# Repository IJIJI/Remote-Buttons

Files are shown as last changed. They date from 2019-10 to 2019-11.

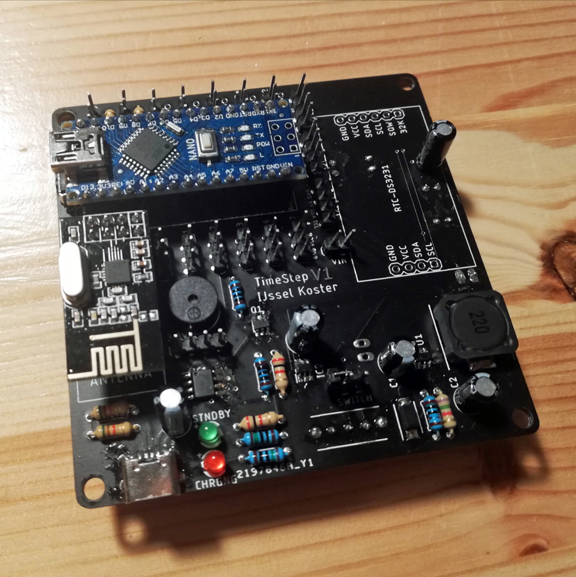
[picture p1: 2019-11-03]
img/Timestep2.jpg

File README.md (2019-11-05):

# TimeStep V0.5
 Timestep V0.5 is the alpha version of the TimeStep hardware platform. 

<!-- <img src="img\Timestep.png" alt="TimeStep V1" style="border-radius:20px; width:40%; margin-left:5%; margin-right:4%; box-shadow: 7px 7px 10px grey;">
<img src="img\Timestep2.jpg" alt="TimeStep V1" style="border-radius:20px; width:40%; margin-left:4%; margin-right:5%; box-shadow: 7px 7px 10px grey;"> -->

## TO DO
* Implement the battery sensor.
* Add a dedicated settings menu.
* Add Classes.
* Add a lapped mode.
* Add a chess mode.
* Add lapptimes to the timed and re-end modes.
* Fix images in readme.md

##### **Prepare for** ***V1.0***
* Add a description.
* Complete adding comments in the code.
* Add wireless connectivity.
  * Complete the pairing menu.
* Change the buttonpressen in the timed modes to the bPress function.

### Fixes
* Fix time set so that all the digits update.
* Fix double press problem
* Fix freezing issue.
* Split into multuple files.
  * Fix Combined branch.
  * Merge Combined branch.

### thoughts
* Add a (esp8266) wifi chip?
* Add interrupts?

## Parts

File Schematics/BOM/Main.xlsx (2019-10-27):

Qty | Value | Device | Package | Parts | Description | Selected: | Ordered
2 |  | LED3MM | LED3MM | CHRGD, CHRGNG | LED | 1
2 |  | MICROBUILDER_SOLDERJUMPERWAVE | MICROBUILDER_SOLDERJUMPER_WAVE | ADDR0, ADDR1 | SMD Solder JUMPER | 1
4 |  | PINHD-1X2 | 1X02 | BATT, BATT_VIN, SWITCH, VIN | PIN HEADER | 1
13 |  | PINHD-1X3 | 1X03 | A0, A1, A2, A3, A6, A7, D2, D3*, D4, D5*, D6*, D7, D8 | PIN HEADER | 1
4 |  | PINHD-1X4 | 1X04 | 3.3V, I2C_1, I2C_2, I2C_3 | PIN HEADER | 1
1 | 0.1/1% (PT2512FK-070R1L) | R-EU_R2512 | R2512 | R17 | RESISTOR, European symbol | 1
1 | 47μF | CPOL-EUE2-5 | E2-5 | C9 | POLARIZED CAPACITOR, European symbol | 1
2 | 22μF | CPOL-EUE2-5 | E2-5 | C1, C2 | POLARIZED CAPACITOR, European symbol | 1
1 | 10μF | CPOL-EUE2-5 | E2-5 | C8 | POLARIZED CAPACITOR, European symbol | 1
2 | 4.7μF | CPOL-EUE2-5 | E2-5 | C4, C5 | POLARIZED CAPACITOR, European symbol | 1
2 | 0.1μF | CPOL-EUE2-5 | E2-5 | C6, C7 | POLARIZED CAPACITOR, European symbol | 1
11 | 10kΩ | R-EU_0204/7 | 0204/7 | R6, R7, R8, R9, R10, R11, R12, R15, R16, R18, R19 | RESISTOR, European symbol | 1
1 | 7.5kΩ | R-EU_0204/7 | 0204/7 | R1 | RESISTOR, European symbol | 1
2 | 5.1kΩ | R-EU_0204/7 | 0204/7 | R20, R21 | RESISTOR, European symbol | 1
1 | 2kΩ | R-EU_0204/7 | 0204/7 | R5 | RESISTOR, European symbol | 1
2 | 1kΩ | R-EU_0204/7 | 0204/7 | R2, R13 | RESISTOR, European symbol | 1
2 | 150Ω | R-EU_0204/7 | 0204/7 | R3, R4 | RESISTOR, European symbol | 1
2 | 100Ω | R-EU_0204/7 | 0204/7 | R14, R22 | RESISTOR, European symbol | 1
1 | 22μH | APW12A45M220 | INDPM125125X450M | L1 | Power Inductors 22uH +/-20% SMD,12.5X12.5mm RoHS | 1
1 | AMS1117-3.3 | AMS1117-3.3 | SOT229P700X180-4N | IC5 | 1A LOW DROPOUT VOLTAGE REGULATOR, SOT-223 | 1
1 | ARDUINO-NANO-3.0 | ARDUINO-NANO-3.0 | ARDUINO-NANO-3.0 | M1 | Arduino Nano 3.0 and compatible devices | 1 | 1
1 | FS312F-G | FS312F-G | SOT95P280X145-6M | IC2 | One Cell Lithium-ion/Polymer Battery Protection IC | 1
1 | FS8205 | FS8205 | FS8205 | Q1 | DUAL N-CHANNEL ENHANCEMENT MODE POWER MOFSET | 1
1 | HNB09A05 | HNB09A05 | HNB09A05 | BUZZER | Buzzers Magnetic YES 3000+/-300Hz 5V 4 ~ 8V 9mm DIP RoHS | 1
1 | INA219AIDR | INA219AIDR | SOIC127P600X175-8N | IC4 | 26-V, Bidirectional, Zero-Drift, High-Side, I2C Out Current/Power Monitor | 1
1 | MCP73831/OT | MCP73831/OT | SOT23-5L | IC1 | MCP73831/2 | 1
1 | MT3608 | MT3608 | SOT95P280X145-6N | U1 | High Efficiency 1.2MHz 2A Step Up Converter | 1
1 | RTC-DS3231-AT24C32 | RTC-DS3231-AT24C32 | RTC-DS3231-AT24C32 | RTC-DS3231 | RTC Module with Battery and EEPROM based on DS3231 and AT24C32 chips | 1 | 1
1 | SS-12F44-G5 | SS-12F44-G5 | SS12F44G5 | S1 | Toggle Switches Plugin RoHS | 1
1 | SS34 | SS34 | DIOM5436X244M | D1 | Schottky Barrier Diodes (SBD) SMA(DO-214AC) RoHS | 1
1 | TS6643ZJ | TS6643ZJ | TS6643ZJ | S2 | Electrical Switches Through Hole | 1
1 | TYPE-C-31-M-17 | TYPE-C-31-M-17 | TYPEC31M17 | J1 | USB Connectors 6 Receptacle 1 RoHS | 1
1 | WIRELESS-NRF24L01 | WIRELESS-NRF24L01 | WIRELESS-NRF24L01 | NRF24L01 | 2.4 GHz Wireless Module based on NRF24L01 chip | 1 | 1

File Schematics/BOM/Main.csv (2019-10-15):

Qty | Value | Device | Package | Parts | Description
2 |  | LED3MM | LED3MM | CHRGD, CHRGNG | LED
2 |  | MICROBUILDER_SOLDERJUMPERWAVE | MICROBUILDER_SOLDERJUMPER_WAVE | ADDR0, ADDR1 | SMD Solder JUMPER
4 |  | PINHD-1X2 | 1X02 | BATT, BATT_VIN, SWITCH, VIN | PIN HEADER
13 |  | PINHD-1X3 | 1X03 | A0, A1, A2, A3, A6, A7, D2, D3*, D4, D5*, D6*, D7, D8 | PIN HEADER
4 |  | PINHD-1X4 | 1X04 | 3.3V, I2C_1, I2C_2, I2C_3 | PIN HEADER
1 | 0.1/1% (PT2512FK-070R1L) | R-EU_R2512 | R2512 | R17 | RESISTOR, European symbol
2 | 0.1uF | CPOL-EUE2-5 | E2-5 | C6, C7 | POLARIZED CAPACITOR, European symbol
2 | 100Ω | R-EU_0204/7 | 0204/7 | R14, R22 | RESISTOR, European symbol
11 | 10kΩ | R-EU_0204/7 | 0204/7 | R6, R7, R8, R9, R10, R11, R12, R15, R16, R18, R19 | RESISTOR, European symbol
1 | 10uF | CPOL-EUE2-5 | E2-5 | C8 | POLARIZED CAPACITOR, European symbol
2 | 150Ω | R-EU_0204/7 | 0204/7 | R3, R4 | RESISTOR, European symbol
1 | 1kΩ | R-EU_0204/7 | 0204/7 | R2 | RESISTOR, European symbol
1 | 2.2kΩ | R-EU_0204/7 | 0204/7 | R5 | RESISTOR, European symbol
1 | 22uH | APW12A45M220 | INDPM125125X450M | L1 | Power Inductors 22uH +/-20% SMD,12.5X12.5mm RoHS
2 | 22μF | CPOL-EUE2-5 | E2-5 | C1, C2 | POLARIZED CAPACITOR, European symbol
1 | 2kΩ | R-EU_0204/7 | 0204/7 | R13 | RESISTOR, European symbol
2 | 4.7μF | CPOL-EUE2-5 | E2-5 | C4, C5 | POLARIZED CAPACITOR, European symbol
1 | 47uF | CPOL-EUE2-5 | E2-5 | C9 | POLARIZED CAPACITOR, European symbol
2 | 5.1kΩ | R-EU_0204/7 | 0204/7 | R20, R21 | RESISTOR, European symbol
1 | 7.5kΩ | R-EU_0204/7 | 0204/7 | R1 | RESISTOR, European symbol
1 | AMS1117-3.3 | AMS1117-3.3 | SOT229P700X180-4N | IC5 | 1A LOW DROPOUT VOLTAGE REGULATOR, SOT-223
1 | ARDUINO-NANO-3.0 | ARDUINO-NANO-3.0 | ARDUINO-NANO-3.0 | M1 | Arduino Nano 3.0 and compatible devices
1 | FS312F-G | FS312F-G | SOT95P280X145-6M | IC2 | One Cell Lithium-ion/Polymer Battery Protection IC
1 | FS8205 | FS8205 | FS8205 | Q1 | DUAL N-CHANNEL ENHANCEMENT MODE POWER MOFSET
1 | HNB09A05 | HNB09A05 | HNB09A05 | BUZZER | Buzzers Magnetic YES 3000+/-300Hz 5V 4 ~ 8V 9mm DIP RoHS
1 | INA219AIDR | INA219AIDR | SOIC127P600X175-8N | IC4 | 26-V, Bidirectional, Zero-Drift, High-Side, I2C Out Current/Power Monitor
1 | MCP73831/OT | MCP73831/OT | SOT23-5L | IC1 | MCP73831/2
1 | MT3608 | MT3608 | SOT95P280X145-6N | U1 | High Efficiency 1.2MHz 2A Step Up Converter
1 | RTC-DS3231-AT24C32 | RTC-DS3231-AT24C32 | RTC-DS3231-AT24C32 | RTC-DS3231 | RTC Module with Battery and EEPROM based on DS3231 and AT24C32 chips
1 | SS-12F44-G5 | SS-12F44-G5 | SS12F44G5 | S1 | Toggle Switches Plugin RoHS
1 | SS34 | SS34 | DIOM5436X244M | D1 | Schottky Barrier Diodes (SBD) SMA(DO-214AC) RoHS
1 | TS6643ZJ | TS6643ZJ | TS6643ZJ | S2 | Electrical Switches Through Hole
1 | TYPE-C-31-M-17 | TYPE-C-31-M-17 | TYPEC31M17 | J1 | USB Connectors 6 Receptacle 1 RoHS
1 | WIRELESS-NRF24L01 | WIRELESS-NRF24L01 | WIRELESS-NRF24L01 | NRF24L01 | 2.4 GHz Wireless Module based on NRF24L01 chip

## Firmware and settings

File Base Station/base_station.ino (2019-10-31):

#include <Arduino.h>
#include <Wire.h>
#include <EEPROM.h>
#include <LiquidCrystal_I2C.h>
#include "RTClib.h"

/*
* Not Up to date.
System with display on uses about 56ma.
System without display uses about 41ma.
*/

LiquidCrystal_I2C lcd(0x27,16,2);  // set the LCD address to 0x27 for a 16 chars and 2 line display
RTC_DS3231 rtc;

//Modes
const char modes[10][11] = {"Timed", "Re-end", "Lapped", "Quiz", "PowerPoint", "Button Set","Time Set", "Pairing", "9", "10"};

// Pinouts
#define buzzer
#define buttonUp 3
#define buttonDown 4
#define buttonMain 5
#define ledMain 6

int buttons = 1; // default terminals + base stations

//#define menuLoop
#define menuMax 7
#define menuMin 1

//The button max limit, increasing this higher than necessary may increase scan times.
#define buttonMax 10

#define screenTimeOut 1

#define setUpAdress 6 // this is how the firmware knows if it has been set up for the first time
#define adress1 7 // Here the button amount is stored

const int EEPid[6] {100, 240, 129, 92, 7, 9}; // This is the code for the firmware to recognize if it has been started before.
const int setUpId = 98;  //This is the code for the firmware to recognize if it has been setup.
//Communication codes.
const int PairCode[buttonMax] {101, 102, 103, 104, 105, 106, 107, 108, 109, 110};
const int trigCode[buttonMax] {151, 152, 153, 154, 155, 156, 157, 158, 159, 160};


// Do not check below if you don't know what you are doing.
int Menu = 1;
int cMenu = 0;
int cHour = 99;
int cMinute = 99;
int cSecond = 99;
bool dispUpdate = false;

bool firstStart = false;


#ifdef screenTimeOut
bool DispOn;
int lastActTime;
#endif

int x;

void setup()
{
  //set the pinmodes.
  pinMode(buttonUp, INPUT_PULLUP); 
  pinMode(buttonDown, INPUT_PULLUP);
  pinMode(buttonMain, INPUT_PULLUP); 
  pinMode(ledMain, OUTPUT);

  // Print an initialization message to the LCD.
  lcd.init();  // initialize the lcd. 
  lcd.backlight(); //Turn on the backlight
  bool DispOn = true; //Let the system know that the display is on.
  lastActTime = secTime(); //Set the last active time to the current time.
  digitalWrite(ledMain, HIGH); //Turn on ledMain for setup.
  lcd.setCursor(2,0);
  lcd.print("initializing");

  if (EEPROMcheck() == false){ // CHeck if the firmware has been started before.
    lcd.print("*");
    firstStart = true;
  }

  lcd.setCursor(0,1);
  lcd.print("[              ]"); //Make a status bar
  delay(200);
  for (x; x <= 13; x++){

    lcd.setCursor(x + 1,1);
    lcd.print("=");
    delay(70); 
  }
  lcd.clear(); //Clear the LCD
  digitalWrite(ledMain, LOW); // Turn off the button ledMain
  if (firstStart == true || EEPROM.read(setUpAdress) != setUpId){ // First time setup.
    prgrm(5);
    prgrm(4);
    if (buttons > 1){
      prgrm(6);
    }
    EEPROM.write(setUpAdress, setUpId);
  }
}


void loop()
{
  DateTime now = rtc.now(); //define rtc.now
  if (digitalRead(buttonMain) == LOW && DispOn == true){ // check if buttonMain is pressed.
    bPress(false);
    prgrm(Menu);
  }
  if (digitalRead(buttonUp) == LOW && DispOn == true){ //check if the buttonUp is pressed
    Menu = Menu + 1;
    while (digitalRead(buttonUp) == LOW){delay(1);}
  }
  if (digitalRead(buttonDown) == LOW && DispOn == true){ //check if the buttonDown is pressed
    Menu = Menu - 1;
    while (digitalRead(buttonDown) == LOW){delay(1);}
  }
  if(Menu > menuMax){ // CHeck if the menu is over the max.
    #ifdef menuLoop
    Menu = menuMin;
    #else
    Menu = menuMax;
    #endif
  }
  if(Menu < menuMin){ //check if the menu is under the min
    #ifdef menuLoop
    Menu = menuMax;
    #else
    Menu = menuMin;
    #endif
  }
  #ifdef screenTimeOut // Manages the backlight.
  if (digitalRead(buttonDown) == LOW || digitalRead(buttonUp) == LOW || digitalRead(buttonMain) == LOW){
    lastActTime = secTime();
    
    while(digitalRead(buttonDown) == LOW || digitalRead(buttonUp) == LOW || digitalRead(buttonMain) == LOW && DispOn == false){delay(1);}
    
  }
  if (secTime() >= lastActTime + 60 * screenTimeOut && DispOn == true){
    lcd.noBacklight();
    DispOn = false;
  }
  else if (secTime() < lastActTime + 60 * screenTimeOut && DispOn == false){
    lcd.backlight();
    DispOn = true;
    dispUpdate = true;
  }
  #endif


  if (Menu != cMenu || dispUpdate == true){ //check if the supposed menu is different from the current menu
    cMenu = Menu;
    lcd.setCursor(0,0);
    lcd.print("                ");
    lcd.setCursor(0,0);
    lcd.print("Mode: ");
    lcd.print(modes[cMenu - 1]);
    delay(200);
  }
  if (now.hour() != cHour || dispUpdate == true){ //check if the current time is different from the supposed time
    cHour = now.hour();
    lcd.setCursor(4,1);
    lcd.print("   ");
    lcd.setCursor(4,1);
    lcdDigitPrint(now.hour(), 2);
    lcd.print(":");
  }
  if (now.minute() != cMinute || dispUpdate == true){ //check if the current time is different from the supposed time
    cMinute = now.minute();
    lcd.setCursor(7,1);
    lcd.print("   ");
    lcd.setCursor(7,1);
    lcdDigitPrint(now.minute(), 2);
    lcd.print(":");
  }
  if (now.second() != cSecond || dispUpdate == true){ //check if the current time is different from the supposed time
    cSecond = now.second();
    lcd.setCursor(10,1);
    lcd.print("   ");
    lcd.setCursor(10,1);
    lcdDigitPrint(now.second(), 2);

  }

  if (dispUpdate == true){
    dispUpdate = false;
  }
}


void lcdDigitPrint(int inVar, int digits){ // A function that prints a variable to the lcd with a fixed digit count.
  int zeros;
  if (inVar < int(pow(10, digits - 1))){
    for(int x = 1; x < digits; x++){
      if(inVar < int(pow(10, x))){
        zeros = digits - x;
        for(x = 1; x <= zeros; x++){
          lcd.print("0");
        }
        lcd.print(inVar);
        break;
      }

    }

  }
  else{
    lcd.print(inVar);
  }
}
void bPress(int sCheck){ //Wait for when button is released + ledMain
  if (sCheck == true){
    while(digitalRead(buttonMain) == LOW){delay(5);}
    while(digitalRead(buttonMain) != LOW){delay(5);}
  }
  digitalWrite(ledMain, HIGH);
  while (digitalRead(buttonMain) == LOW){delay(5);}
  digitalWrite(ledMain, LOW);
  // delay(20);
}

int getMil(float sec){ // Converts inputted seconds to minutes and seconds and returns the remainder.
  int sec2 = sec * 100;
  sec = sec2 % 100;
  return abs(sec);
}
int getSec(float sec){ // Converts inputted seconds to miliseconds, seconds and minutes and returns seconds.
  int sec2 = sec;
  sec = sec2 % 60;
  return sec;

}
int getMin(float sec){ // Converts inputted seconds to miliseconds seconds and minutes and returns minutes.
  int sec2 = sec;
  int mins;
  mins = round((sec2 / 60));
  return mins;
}
int secTime() { // gets the current time in seconds (mith a descimal)
  DateTime now = rtc.now();
  int secTime;
  secTime = now.second() + now.minute() * 60 + now.hour() * 60 * 60;
  return secTime;
}
int timeDiv(int x){ //gets the time depending on the number.
  DateTime now = rtc.now();
  int result;
  if (x == 0){
    result = now.hour();
  }
  else if (x == 1){
    result = now.minute();
  }
  else if (x == 2){
    result = now.second();
  }
  return result;

}
int EEPROMcheck(){ // compares the eeprom for the EEPid's and returns false if unfamiliar and rewrites the eeprom to EEPid.
  bool familiar = true;
  for(int x = 0; x < 6; x++){
    if (EEPROM.read(x) != EEPid[x]){
      familiar = false;
    }
  }
  if (familiar == false){
    for (int x = 0; x < EEPROM.length(); x++){
      EEPROM.write(x, 0);
    }
    for (int x = 0; x < 6; x++){
      EEPROM.write(x, EEPid[x]);
    }
    EEPROM.write(adress1, buttons);
  }
  if (familiar == true){
    buttons = EEPROM.read(adress1);
  }
  return familiar;
}



//TODO VV should be moved to seperate files

void prgrm(int menu) { // these are the different programs found in the menu.
  DateTime now = rtc.now();
  
  if (menu == 1 || menu == 2)
  {
    int pedButtons = 0;
    int bMenu = 3;
    int cBMenu = 99;
    float tStart = 0;
    float time = 0;
    int actived[buttonMax] = {0, 0, 0, 0, 0, 0, 0, 0, 0, 0}; 

    bool buttonMainActive = 0;

    lcd.clear();
    lcd.setCursor(0,0);
    lcd.print("Time:");
    lcd.setCursor(1,1);
    lcd.print("Press to start");
    while(digitalRead(buttonMain) != LOW){delay(5);}
    digitalWrite(ledMain, HIGH);
    while(digitalRead(buttonMain) == LOW){delay(5);}
    lcd.clear();
    lcd.setCursor(0,0);
    lcd.print("Time:");
    lcd.setCursor(0,1);
    lcd.print("Left:");
    tStart = millis();
    while(pedButtons < buttons){
      time = (millis() - tStart) / 1000;
      lcd.setCursor(6, 0);
      lcdDigitPrint(getMin(time), 2);
      lcd.print(":");
      lcdDigitPrint(getSec(time), 2);
      lcd.print(".");
      lcd.print(getMil(time));
      lcd.setCursor(6,1);
      lcd.print(buttons-pedButtons);
      if (digitalRead(buttonMain) == LOW || actived[0] == 1){
        actived[0] = 1;
        digitalWrite(ledMain, LOW);
      }
      for (int x = 1; x <= buttons; x++){
        //check if input car = trigCode[x - 1]
      }
      pedButtons = 0;
      for (int x = 0; x <= buttons; x++){
        pedButtons = pedButtons + actived[x];
      }

      

    }
    lcd.setCursor(6,1);
    lcd.print("Completed!");
    bPress(true);
    
    


  }
  else if (menu == 3){
    float tStart;
    float time;
    double lapTime[] = {};
    int laps = 0;

    int tMenu = 0;
    int CtMenu = 99;

    lcd.clear();
    lcd.setCursor(0,0);
    lcd.print("Time:");
    lcd.setCursor(1,1);
    lcd.print("Press to start");
    while(digitalRead(buttonMain) != LOW){delay(5);}
    digitalWrite(ledMain, HIGH);
    while(digitalRead(buttonMain) == LOW){delay(5);}
    lcd.clear();
    lcd.setCursor(0,0);
    lcd.print("Time:");
    lcd.setCursor(0,1);
    lcd.print("Laps:");
    tStart = millis();
    while(digitalRead(buttonUp) == HIGH && digitalRead(buttonDown) == HIGH){
      time = (millis() - tStart) / 1000;
      lcd.setCursor(6, 0);
      lcdDigitPrint(getMin(time), 2);
      lcd.print(":");
      lcdDigitPrint(getSec(time), 2);
      lcd.print(".");
      lcd.print(getMil(time));
      lcd.setCursor(6,1);
      lcd.print(laps);
      if (digitalRead(buttonMain) == LOW /* || Radio signal == active */){
        lapTime[laps] = time;
        laps++; 
      }

    }
    
    while (digitalRead(buttonMain) == HIGH){
      
      if (digitalRead(buttonUp) == LOW && cMenu < laps - 1){
        cMenu++;
      }
      if (digitalRead(buttonDown) == LOW && cMenu > 0){
        cMenu--;
      }
    
      if (tMenu != CtMenu){  
        CtMenu = tMenu;
        lcd.setCursor(0,0);
        lcd.print(tMenu);
        lcd.print(": ");
        lcdDigitPrint(getMin(lapTime[tMenu]), 2);
        lcd.print(":");
        lcdDigitPrint(getSec(lapTime[tMenu]), 2);
        lcd.print(".");
        lcd.print(getMil(lapTime[tMenu]));
        
        lcd.setCursor(0,1);
        lcd.print(tMenu + 1);
        lcd.print(": ");
        lcdDigitPrint(getMin(lapTime[tMenu + 1]), 2);
        lcd.print(":");
        lcdDigitPrint(getSec(lapTime[tMenu + 1]), 2);
        lcd.print(".");
        lcd.print(getMil(lapTime[tMenu + 1]));
      
      }

    }
    bPress(false);
  }
  else if (menu == 4){
    int bPressd = 999;
    lcd.clear();
    lcd.setCursor(6,0);
    lcd.print("Quiz");
    lcd.setCursor(1,1);
    lcd.print("Press To Start");
    bPress(true);
    
  }
  else if (menu == 6){

    int cButtons = 99;
    lcd.clear();
    lcd.setCursor(0,0);
    lcd.print("Stations:");
    while(digitalRead(buttonMain) == LOW){delay(1);}
    while(digitalRead(buttonMain) != LOW){
      if (digitalRead(buttonUp) == LOW && buttons < buttonMax){
        buttons = buttons + 1;
        while(digitalRead(buttonUp) == LOW){delay(1);}
      }
      if (digitalRead(buttonDown) == LOW && buttons > 1){
        buttons = buttons - 1;
        while(digitalRead(buttonDown) == LOW){delay(1);}
      }

      if (cButtons != buttons){
        cButtons = buttons;
        lcd.setCursor(10, 0);
        lcd.print("       ");
        lcd.setCursor(10, 0);
        lcd.print(buttons);
      }
      

    }
    EEPROM.write(adress1, buttons);
    dispUpdate = true;
    lastActTime = secTime();
    bPress(false);
  }
  else if(menu == 7){

    int cTimeEdit = 0;
    char tOffset[3] = {0, 0, 0};
    const char tMaxLimits[3] = {24, 60, 60};
    char cSetTime[3] = {0, 0, 0};
    const char timeLocs[3] = {4, 7, 10};
    while(digitalRead(buttonMain) == LOW){delay(1);}
    lcd.clear();
    lcd.setCursor(0,0);
    lcd.print("Time:");
    while(cTimeEdit <= 2){

      if (timeDiv(cTimeEdit) + tOffset[cTimeEdit] != cSetTime[cTimeEdit] || timeDiv(cTimeEdit) + tOffset[cTimeEdit] == 0){ //check if the current time is different from the supposed time
        cSetTime[cTimeEdit] = timeDiv(cTimeEdit) + tOffset[cTimeEdit];
        lcd.setCursor(timeLocs[cTimeEdit],1);
        lcd.print("   ");
        lcd.setCursor(timeLocs[cTimeEdit],1);
        lcdDigitPrint(timeDiv(cTimeEdit) + tOffset[cTimeEdit], 2);
        if (cTimeEdit != 2){ 
          lcd.print(":");
        }
      }
      if (digitalRead(buttonMain) == LOW){
        cTimeEdit = cTimeEdit + 1;
        bPress(false);
      }
      if (digitalRead(buttonUp) == LOW && timeDiv(cTimeEdit) + tOffset[cTimeEdit] < tMaxLimits[cTimeEdit]){
        tOffset[cTimeEdit] = tOffset[cTimeEdit] + 1;
        while(digitalRead(buttonUp) == LOW){delay(1);}
      }
      if (digitalRead(buttonDown) == LOW && timeDiv(cTimeEdit) + tOffset[cTimeEdit] > 0){ 
        tOffset[cTimeEdit] = tOffset[cTimeEdit] - 1;
        while (digitalRead(buttonDown) == LOW){delay(1);}
      }
      
    }
    int hTime = timeDiv(0) + tOffset[0];
    int mTime = timeDiv(1) + tOffset[1];
    int sTime = timeDiv(2) + tOffset[2];
    rtc.adjust(DateTime(2019, 10, 15, hTime, mTime, sTime));


  }
  else if (menu == 7){
    while (digitalRead(buttonMain) == LOW){delay(1);}
    lcd.clear();
    lcd.setCursor(0,0);
    lcd.print("Hold Pair On");
    lcd.setCursor(0,1);
    lcd.print("Button:");
    for(int x = 2; x <= buttons; x++){
      lcd.setCursor(8,1);
      lcd.print("        ");
      lcd.setCursor(8,1);
      lcd.print(x);
      bPress(true);
      // send paircode paircode[x] to transmitters  
      // delay(300);
    }
    lcd.clear();
    if (buttons > 1){
      lcd.setCursor(0,0);
      lcd.print("Pairing complete!");
    }
    else {
      lcd.setCursor(3,0);
      lcd.print("No Buttons");
      lcd.setCursor(4,1);
      lcd.print("To Pair!");
    }
    delay(1000);
      
  }
  lcd.clear();
  dispUpdate = true;
  lastActTime = secTime();


}

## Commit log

2019-09-21 Fixed Time set 0 problem and led support
    [base_station.ino]
2019-09-21 Added a PCB Schematic.
    [station v1.fzz]
2019-09-22 Completed LED integration
2019-09-22 Added schematic v1
    [station v1.fzz]
2019-09-25 added pulldown resistors to pcb
    [station PCB v1.fzz]
2019-09-27 added minute formating to timer.
2019-09-27 Fixed the timer display format
    [base_station.ino]
2019-10-01 Added arduino.json to gitignore
    [station PCB v1+.fzz, station PCB v1.fzz]
2019-10-06 Added BOM
    [Main.csv]
2019-10-15 added rf library
    [Main.csv, Main.xlsx, station PCB v1+.fzz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]
2019-10-21 Revert "Changed back to single file, see combined"
    This reverts commit 0e1d58947b35420be689b455369c2b491d9700fd.
    [base_station.ino]
2019-10-21 Revert "Revert "Changed back to single file, see combined""
    This reverts commit f698fb8d14c6b5069cf7f1855aeea066a9f7036f.
    [base_station.ino]
2019-10-27 Updated a parts list
    [Main.xlsx]
2019-10-29 Added a prototype of the Lapped mode
